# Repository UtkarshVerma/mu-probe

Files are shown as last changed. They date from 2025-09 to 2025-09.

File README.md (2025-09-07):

# μProbe

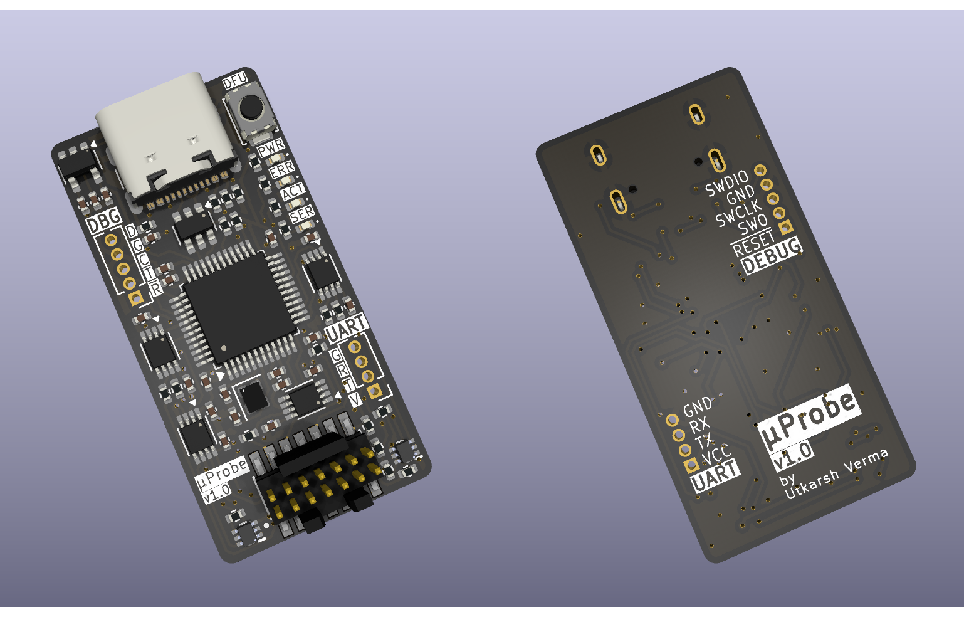
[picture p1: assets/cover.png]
3D render of the project


This probe is my personal take on the [Black Magic Debug][bmp] project's [Black Magic Probe v2.1][bmp-2.1]. I was disappointed to find out that I could not use my STLink v3 on non-ST targets[^1], even when they used the same protocol. One thing led to another and I stumbled upon the Black Magic Probe. The idea of having a configurable debugger appealed to me. This combined with an itch to work on a hardware project is what brought μProbe into existence.

> [!note]
> Please buy the official Black Magic Probe if you can! It is necessary to support the awesome work that the folks at the Black Magic project do.

## Possible future improvements

- Improve nASSERT_TVREF circuitry.
- Switch to a more powerful MCU.
- Add USB-C power negotiation.
- Add AUX connector from BMP v2.3.

## Credits

This project would not have been possible without the following resources:

- [Black Magic Debug v2.1e schematic][bmp]
- 3D models:
  - [4-pin SMT crystal osciallator by Steven Minichiello][xtal]

Lastly, I would also like to thank the warm community at 1BitSquared's Discord server for their insights and help.

[bmp]: https://black-magic.org/
[bmp-2.1]: https://black-magic.org/hardware.html#black-magic-probe-mini-v2-1-bmp21
[xtal]: https://grabcad.com/library/sitime-2016-4-pin-smt-mems-crystal-oscillator-to-20-ppm-1

[^1]: https://sourceforge.net/p/openocd/tickets/275/

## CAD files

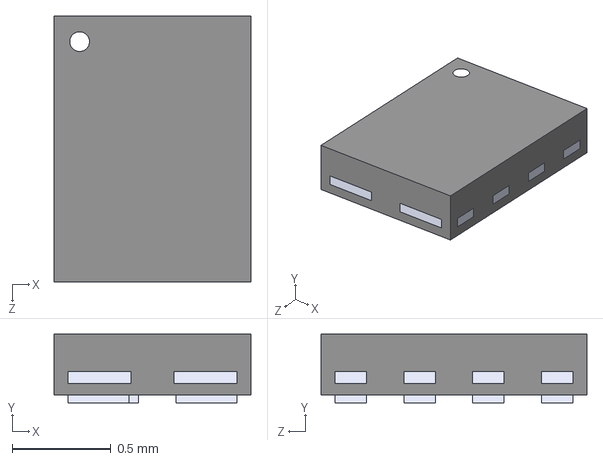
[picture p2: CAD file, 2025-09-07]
models/PSON35P135X100X35-8N.step
1.00 x 0.35 x 1.35 mm

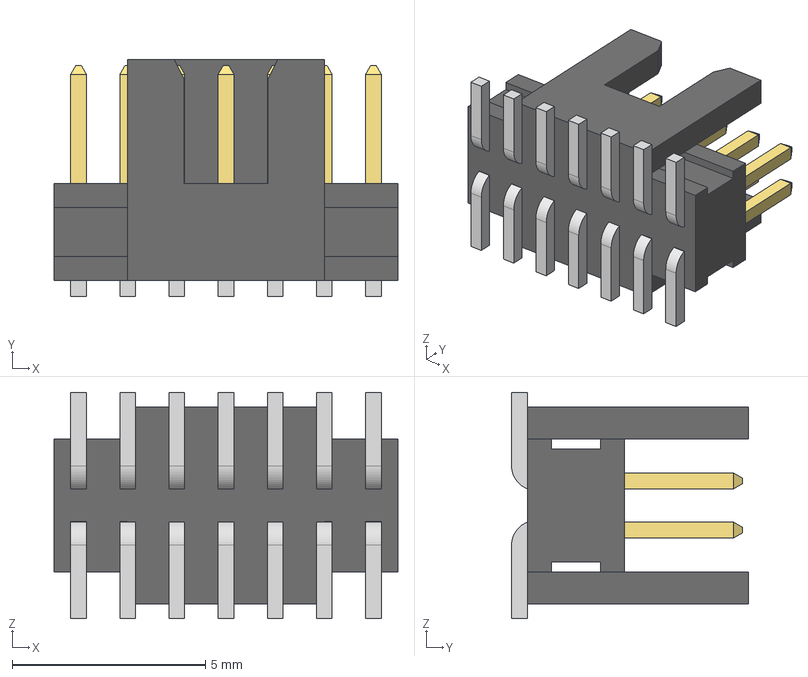
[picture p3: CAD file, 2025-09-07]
models/FTSH-107-01-L-DV-K.stp
8.89 x 6.12 x 5.84 mm
FTSH-107-01-L-DV-K_body
FTSH-107-01-L-DV-K_pins1
FTSH-107-01-L-DV-K_pins2

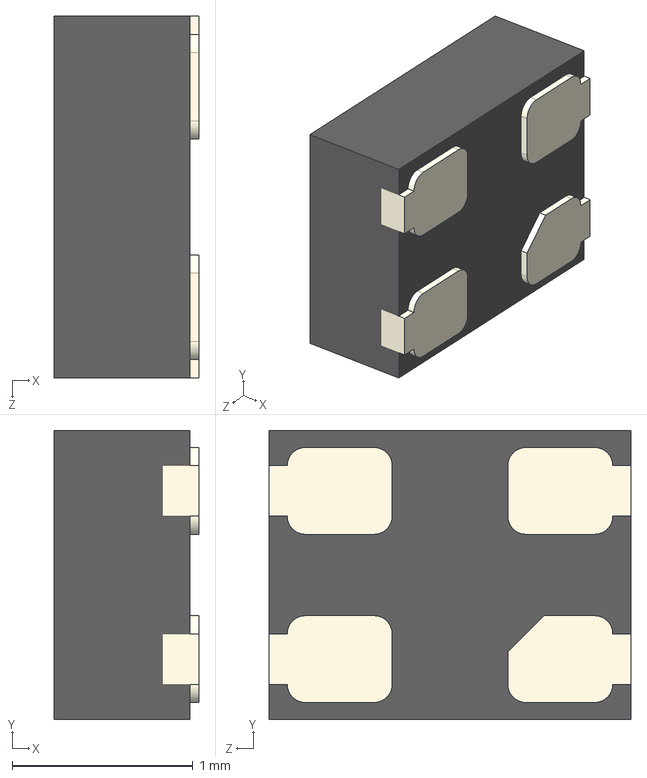
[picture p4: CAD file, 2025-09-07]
models/QFN_2016_4pins.STEP
0.8 x 1.60 x 2.00 mm

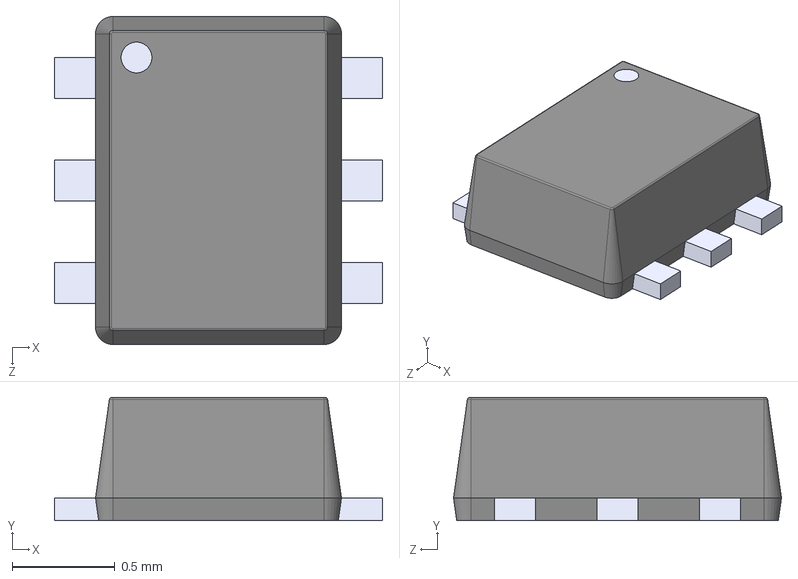
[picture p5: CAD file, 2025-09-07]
models/SOTFL50P162X60-6N.step
1.60 x 0.6 x 1.60 mm

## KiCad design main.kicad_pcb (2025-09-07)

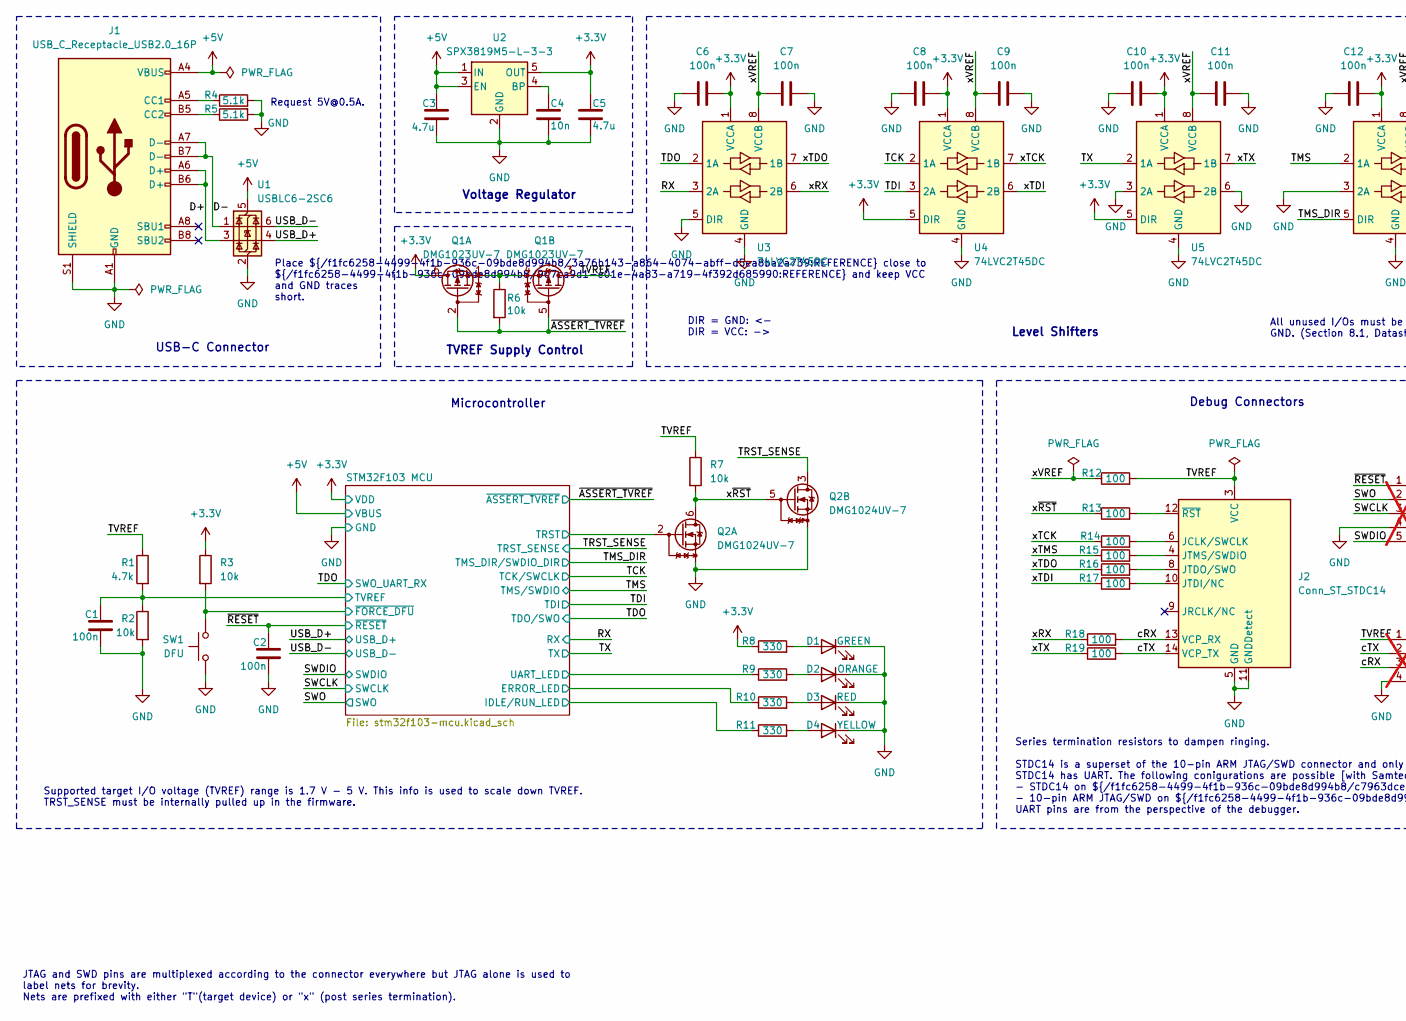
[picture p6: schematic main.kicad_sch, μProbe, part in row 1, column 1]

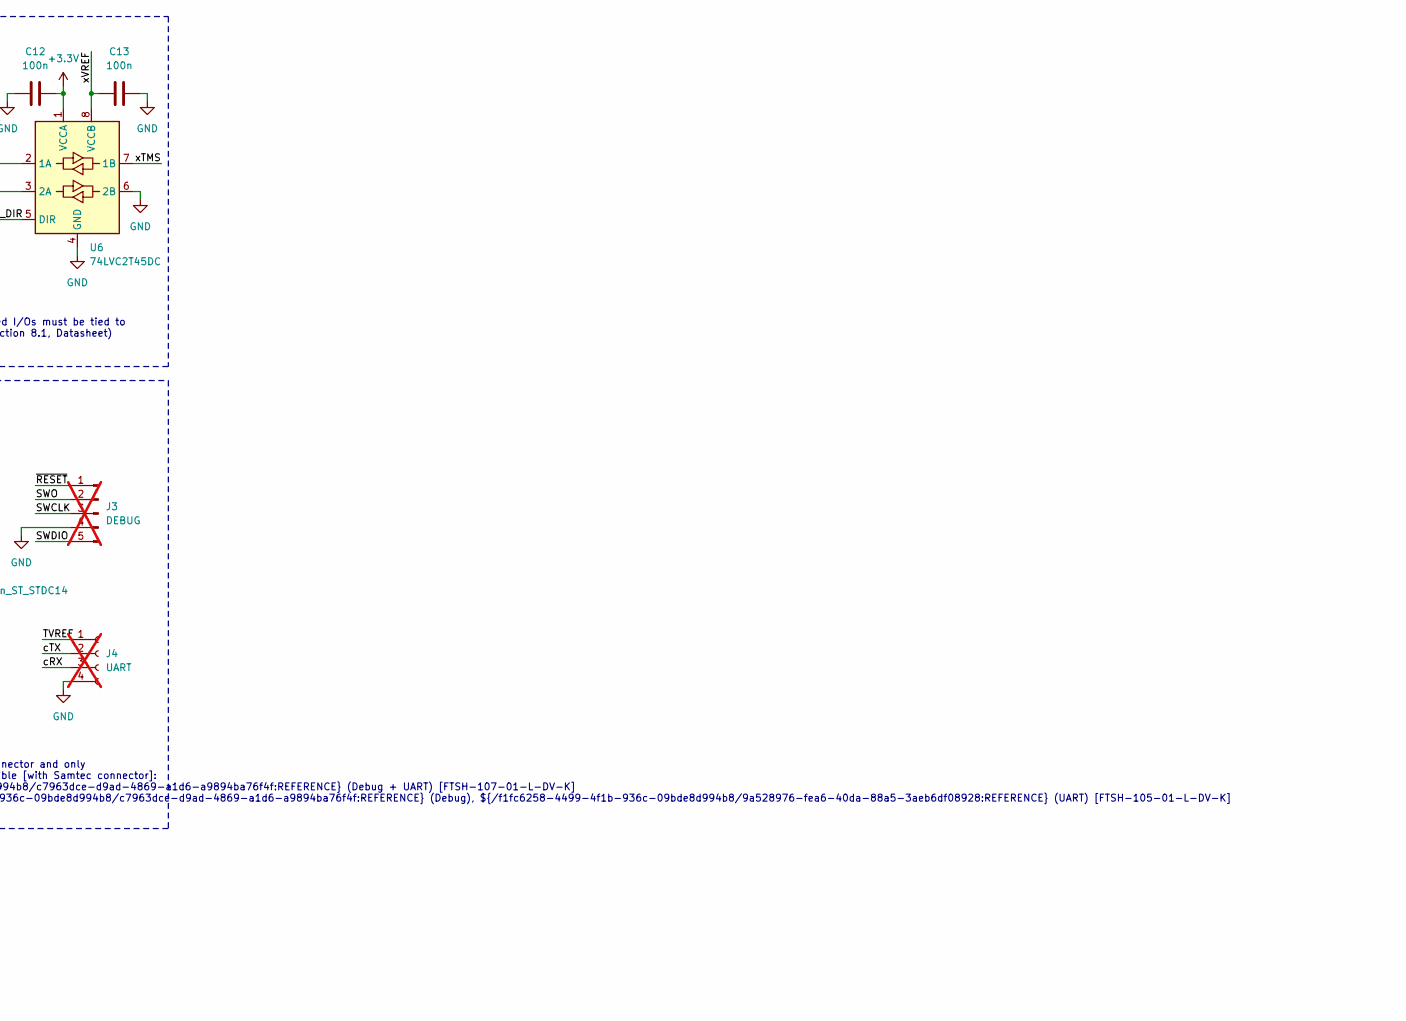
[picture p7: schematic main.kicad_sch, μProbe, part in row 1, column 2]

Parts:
C1, C2, C6, C7, C8, C9, C10, C11, C12, C13: 100n; C_0402_1005Metric; LCSC Part C60474
C3, C5: 4.7u; C_0402_1005Metric; LCSC Part C23733
C4: 10n; C_0402_1005Metric; LCSC Part C15195
D1: GREEN; LED_0402_1005Metric; LCSC Part C2980183
D2: ORANGE; LED_0402_1005Metric; LCSC Part C779448
D3: RED; LED_0402_1005Metric; LCSC Part C136765
D4: YELLOW; LED_0402_1005Metric; LCSC Part C20608782
J1: USB_C_Receptacle_USB2.0_16P; USB_C_Receptacle_GCT_USB4105-xx-A_16P_TopMnt_Horizontal; LCSC Part C2988369
J2: Conn_ST_STDC14; SAMTEC_FTSH-107-01-L-DV-K; LCSC Part C46971079
J3: DEBUG; PinHeader_1x05_P1.27mm_Vertical; not fitted
J4: UART; PinHeader_1x04_P1.27mm_Vertical; not fitted
Q1: DMG1023UV-7; SOTFL50P162X60-6N; LCSC Part C212298
Q2: DMG1024UV-7; SOTFL50P162X60-6N; LCSC Part C2759893
R1: 4.7k; R_0402_1005Metric; LCSC Part C105871
R2, R3, R6, R7: 10k; R_0402_1005Metric; LCSC Part C60490
R4, R5: 5.1k; R_0402_1005Metric; LCSC Part C25905
R8, R9, R10, R11: 330; R_0402_1005Metric; LCSC Part C105875
R12, R13, R14, R15, R16, R17, R18, R19: 100; R_0402_1005Metric; LCSC Part C106232
SW1: DFU; SW_Push_SPST_NO_Alps_SKRK; LCSC Part C720477
U1: USBLC6-2SC6; SOT-23-6; LCSC Part C7519
U2: SPX3819M5-L-3-3; SOT-23-5; LCSC Part C9055
U3, U4, U5, U6: 74LVC2T45DC; VSSOP-8_2.3x2mm_P0.5mm; LCSC Part C15741

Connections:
+3.3V: C5.1, C6.1, C8.1, C10.1, C12.1, Q1.6 (D), R3.1, R8.1, U2.5 (OUT), U3.1 (VCCA), U4.1 (VCCA), U4.5 (DIR), U5.1 (VCCA), U5.5 (DIR), U6.1 (VCCA); also elsewhere on the board
+5V: C3.1, J1.A4 (VBUS), J1.A9 (VBUS), J1.B4 (VBUS), J1.B9 (VBUS), U1.5 (VBUS), U2.1 (IN), U2.3 (EN); also elsewhere on the board
/D+: J1.A6 (D+), J1.B6 (D+), U1.3 (I/O2)
/D-: J1.A7 (D-), J1.B7 (D-), U1.1 (I/O1)
/RX: U3.3 (2A); also elsewhere on the board
/STM32F103 MCU/ERROR_LED: R10.1; also elsewhere on the board
/STM32F103 MCU/IDLE/RUN_LED: R11.1; also elsewhere on the board
/STM32F103 MCU/TRST: Q2.2 (G); also elsewhere on the board
/STM32F103 MCU/TVREF: C1.1, R1.2, R2.1; also elsewhere on the board
/STM32F103 MCU/UART_LED: R9.1; also elsewhere on the board
/STM32F103 MCU/~FORCE_DFU: R3.2, SW1.2; also elsewhere on the board
/SWCLK: J3.3; also elsewhere on the board
/SWDIO: J3.5; also elsewhere on the board
/SWO: J3.2; also elsewhere on the board
/TCK: U4.2 (1A); also elsewhere on the board
/TDI: U4.3 (2A); also elsewhere on the board
/TDO: U3.2 (1A); also elsewhere on the board
/TMS: U6.2 (1A); also elsewhere on the board
/TMS_DIR: U6.5 (DIR); also elsewhere on the board
/TRST_SENSE: Q2.3 (D); also elsewhere on the board
/TVREF: J2.3 (VCC), J4.1, Q1.3 (D), R1.1, R7.1, R12.2
/TX: U5.2 (1A); also elsewhere on the board
/USB_D+: U1.4 (I/O2); also elsewhere on the board
/USB_D-: U1.6 (I/O1); also elsewhere on the board
/cRX: J2.13 (VCP_RX), J4.3, R18.2
/cTX: J2.14 (VCP_TX), J4.2, R19.2
/xRX: R18.1, U3.6 (2B)
/xTCK: R14.1, U4.7 (1B)
/xTDI: R17.1, U4.6 (2B)
/xTDO: R16.1, U3.7 (1B)
/xTMS: R15.1, U6.7 (1B)
/xTX: R19.1, U5.7 (1B)
/xVREF: C7.2, C9.2, C11.2, C13.2, R12.1, U3.8 (VCCB), U4.8 (VCCB), U5.8 (VCCB), U6.8 (VCCB)
/x~RST: Q2.5 (G), Q2.6 (D), R7.2, R13.1
/~ASSERT_TVREF: Q1.2 (G), Q1.5 (G), R6.2; also elsewhere on the board
/~RESET: C2.2, J3.1; also elsewhere on the board
GND: C1.2, C2.1, C3.2, C4.2, C5.2, C6.2, C7.1, C8.2, C9.1, C10.2, C11.1, C12.2, C13.1, D1.1 (K), D2.1 (K), D3.1 (K), D4.1 (K), J1.A1 (GND), J1.A12 (GND), J1.B1 (GND), J1.B12 (GND), J1.S1 (SHIELD), J2.5 (GND), J2.7 (GND), J2.11 (GNDDetect), J3.4, J4.4, Q2.1 (S), Q2.4 (S), R2.2, R4.2, R5.2, SW1.1, U1.2 (GND), U2.2 (GND), U3.4 (GND), U3.5 (DIR), U4.4 (GND), U5.3 (2A), U5.4 (GND), U5.6 (2B), U6.3 (2A), U6.4 (GND), U6.6 (2B); also elsewhere on the board
unnamed: D1.2 (A), R8.2
unnamed: D2.2 (A), R9.2
unnamed: D3.2 (A), R10.2
unnamed: D4.2 (A), R11.2
unnamed: J1.A5 (CC1), R4.1
unnamed: J1.B5 (CC2), R5.1
unnamed: J2.6 (JCLK/SWCLK), R14.2
unnamed: J2.10 (JTDI/NC), R17.2
unnamed: J2.8 (JTDO/SWO), R16.2
unnamed: J2.4 (JTMS/SWDIO), R15.2
unnamed: J2.12 (~RST), R13.2
unnamed: Q1.1 (S), Q1.4 (S), R6.1
unnamed: C4.1, U2.4 (BP)

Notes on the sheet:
Debug Connectors
TVREF Supply Control
Request 5V@0.5A.
Series termination resistors to dampen ringing. STDC14 is a superset of the 10-pin ARM JTAG/SWD connector and only STDC14 has UART. The following conigurations are possible [with Samtec connector]: - STDC14 on ${/f1fc6258-4499-4f1b-936c-09bde8d994b8/c7963dce-d9ad-4869-a1d6-a9894ba76f4f:REFERENCE} (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
Level Shifters
All unused I/Os must be tied to GND. (Section 8.1, Datasheet)
JTAG and SWD pins are multiplexed according to the connector everywhere but JTAG alone is used to label nets for brevity. Nets are prefixed with either "T"(target device) or "x" (post series termination).
USB-C Connector
Supported target I/O voltage (TVREF) range is 1.7 V - 5 V. This info is used to scale down TVREF. TRST_SENSE must be internally pulled up in the firmware.
Place ${/f1fc6258-4499-4f1b-936c-09bde8d994b8/3a76b143-a864-4074-abff-d5ea8ba2a739:REFERENCE} close to ${/f1fc6258-4499-4f1b-936c-09bde8d994b8/907ca9d1-e01e-4a83-a719-4f392d685990:REFERENCE} and keep VCC and GND traces short.
Voltage Regulator
DIR = GND: <- DIR = VCC: ->
Microcontroller

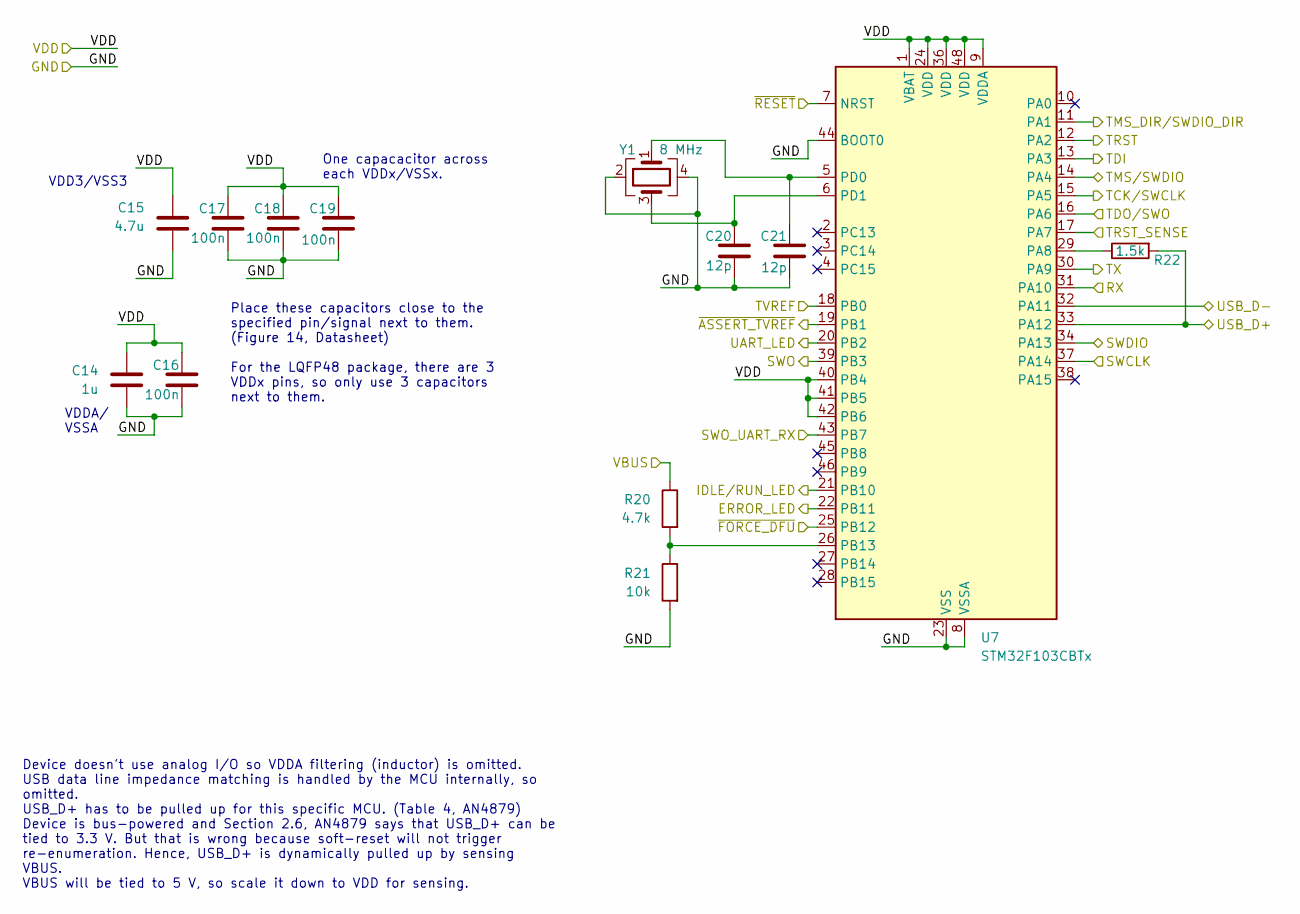
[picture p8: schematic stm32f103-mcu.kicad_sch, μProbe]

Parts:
C14: 1u; C_0402_1005Metric; LCSC Part C14445
C15: 4.7u; C_0402_1005Metric; LCSC Part C23733
C16, C17, C18, C19: 100n; C_0402_1005Metric; LCSC Part C60474
C20, C21: 12p; C_0402_1005Metric; LCSC Part C106201
R20: 4.7k; R_0402_1005Metric; LCSC Part C105871
R21: 10k; R_0402_1005Metric; LCSC Part C60490
R22: 1.5k; R_0402_1005Metric; LCSC Part C114759
U7: STM32F103CBTx; LQFP-48_7x7mm_P0.5mm; LCSC Part C8304
Y1: 8 MHz; Crystal_4P_GND24; LCSC Part C400090

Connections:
+3.3V: C14.1, C15.1, C16.1, C17.1, C18.1, C19.1, U7.1 (VBAT), U7.9 (VDDA), U7.24 (VDD), U7.36 (VDD), U7.40 (PB4), U7.41 (PB5), U7.42 (PB6), U7.48 (VDD); also elsewhere on the board
+5V: R20.1; also elsewhere on the board
/RX: U7.31 (PA10); also elsewhere on the board
/STM32F103 MCU/ERROR_LED: U7.22 (PB11); also elsewhere on the board
/STM32F103 MCU/IDLE/RUN_LED: U7.21 (PB10); also elsewhere on the board
/STM32F103 MCU/TRST: U7.12 (PA2); also elsewhere on the board
/STM32F103 MCU/TVREF: U7.18 (PB0); also elsewhere on the board
/STM32F103 MCU/UART_LED: U7.20 (PB2); also elsewhere on the board
/STM32F103 MCU/~FORCE_DFU: U7.25 (PB12); also elsewhere on the board
/SWCLK: U7.37 (PA14); also elsewhere on the board
/SWDIO: U7.34 (PA13); also elsewhere on the board
/SWO: U7.39 (PB3); also elsewhere on the board
/TCK: U7.15 (PA5); also elsewhere on the board
/TDI: U7.13 (PA3); also elsewhere on the board
/TDO: U7.16 (PA6), U7.43 (PB7); also elsewhere on the board
/TMS: U7.14 (PA4); also elsewhere on the board
/TMS_DIR: U7.11 (PA1); also elsewhere on the board
/TRST_SENSE: U7.17 (PA7); also elsewhere on the board
/TX: U7.30 (PA9); also elsewhere on the board
/USB_D+: R22.2, U7.33 (PA12); also elsewhere on the board
/USB_D-: U7.32 (PA11); also elsewhere on the board
/~ASSERT_TVREF: U7.19 (PB1); also elsewhere on the board
/~RESET: U7.7 (NRST); also elsewhere on the board
GND: C14.2, C15.2, C16.2, C17.2, C18.2, C19.2, C20.2, C21.2, R21.2, U7.8 (VSSA), U7.23 (VSS), U7.35 (VSS), U7.44 (BOOT0), U7.47 (VSS), Y1.2, Y1.4; also elsewhere on the board
unnamed: R22.1, U7.29 (PA8)
unnamed: R20.2, R21.1, U7.26 (PB13)
unnamed: C21.1, U7.5 (PD0), Y1.1
unnamed: C20.1, U7.6 (PD1), Y1.3

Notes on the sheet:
One capacacitor across each VDDx/VSSx.
Device doesn't use analog I/O so VDDA filtering (inductor) is omitted. USB data line impedance matching is handled by the MCU internally, so omitted. USB_D+ has to be pulled up for this specific MCU. (Table 4, AN4879) Device is bus-powered and Section 2.6, AN4879 says that USB_D+ can be tied to 3.3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
VDDA/ VSSA
VDD3/VSS3
Place these capacitors close to the specified pin/signal next to them. (Figure 14, Datasheet) For the LQFP48 package, there are 3 VDDx pins, so only use 3 capacitors next to them.

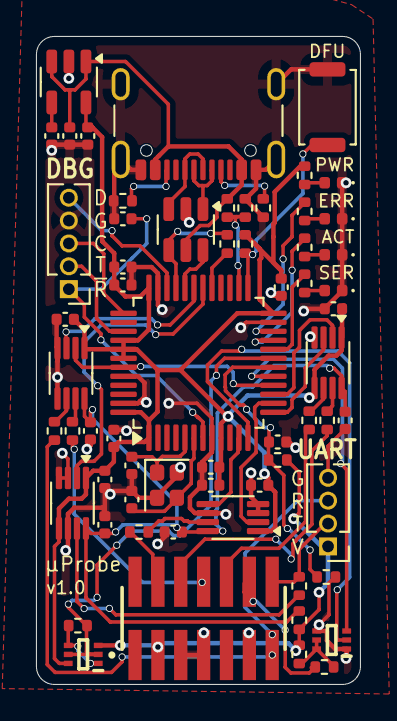
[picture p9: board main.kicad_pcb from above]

Board: 2 copper layers, 18.0 x 36.0 mm, 62 parts (0 on the bottom side), 54 nets.

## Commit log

2025-09-07 schematic: initial design with stm32f103
    [DMG1024UV-7.step, main.kicad_pcb, main.kicad_sch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]
2025-09-07 layout: initial design with added LCSC part metadata
    [FTSH-107-01-L-DV-K.stp, PSON35P135X100X35-8N.step, QFN_2016_4pins.STEP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]
2025-09-07 schematic: fix C4 LCSC part number and STM32F1 component variant
    The BMP firmware cannot be flashed onto the STM32F103C8Tx (64 KiB
    variant) due to size constraints. The STM32F103CBUx was used in the
    reference schematic but somehow got overlooked during the design.
    [main.kicad_sch, stm32f103-mcu.kicad_sch]
2025-09-07 layout: update from schematic and add license
    [main.kicad_pcb]
2025-09-07 layout: fix crystal footprint-model linking and update layout
    [main.kicad_pcb]
2025-09-07 schematic: fix LCSC part number for STM32F1 MCU
    [main.kicad_pcb, stm32f103-mcu.kicad_sch]

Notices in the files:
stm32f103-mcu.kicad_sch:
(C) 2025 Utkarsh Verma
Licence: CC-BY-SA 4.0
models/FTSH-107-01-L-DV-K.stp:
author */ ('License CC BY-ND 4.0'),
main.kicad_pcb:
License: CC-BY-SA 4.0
